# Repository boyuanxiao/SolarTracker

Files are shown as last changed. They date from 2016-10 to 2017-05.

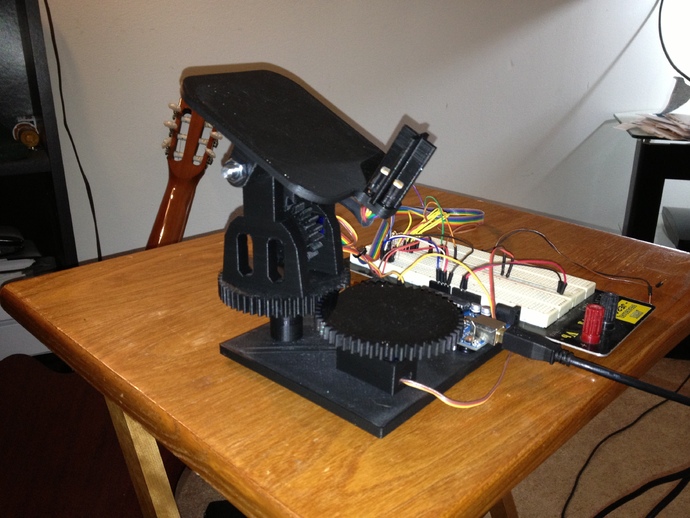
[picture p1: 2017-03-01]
cad/3dprint/images/Dual_Axis_Tracker_Front_preview_featured.jpg

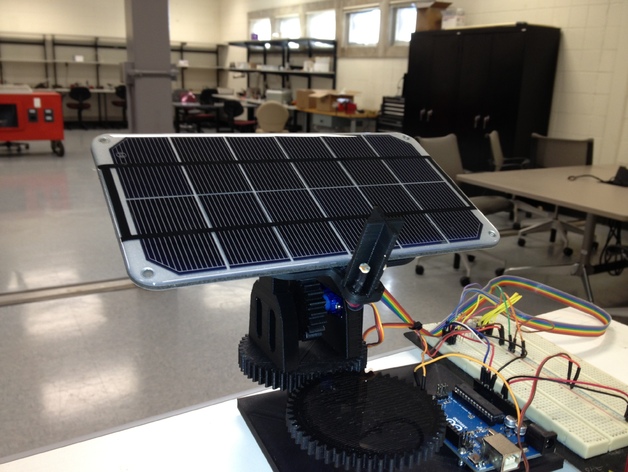
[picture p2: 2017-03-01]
cad/3dprint/images/photo_1_preview_featured.jpg

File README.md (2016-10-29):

# SolarTracker

Hardware and software for a servo controlled solar panel which orients itself to face directly towards the sun.

Plan to to have two modes of operation:

-Sensor: uses photodiode sensors to try and find the brightest source of light

-Auto: servo rotates as directed by a look up table based on the trajectory of the sun

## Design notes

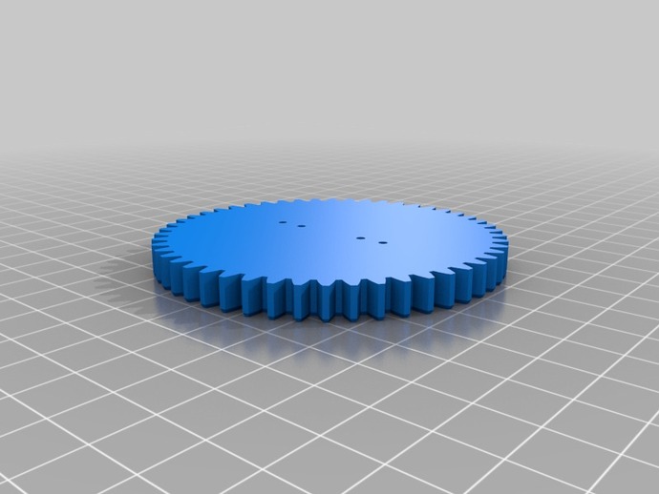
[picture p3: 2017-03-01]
cad/3dprint/images/Horz_Servo_Gear_preview_featured.jpg

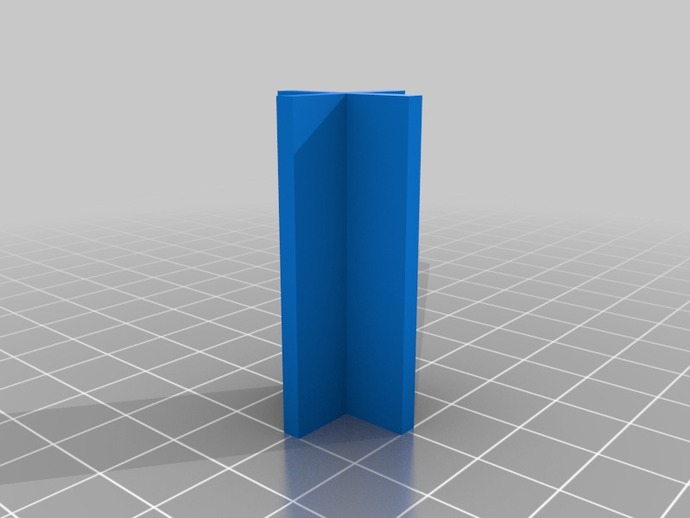
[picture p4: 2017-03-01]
cad/3dprint/images/LDR_Divider_preview_featured.jpg

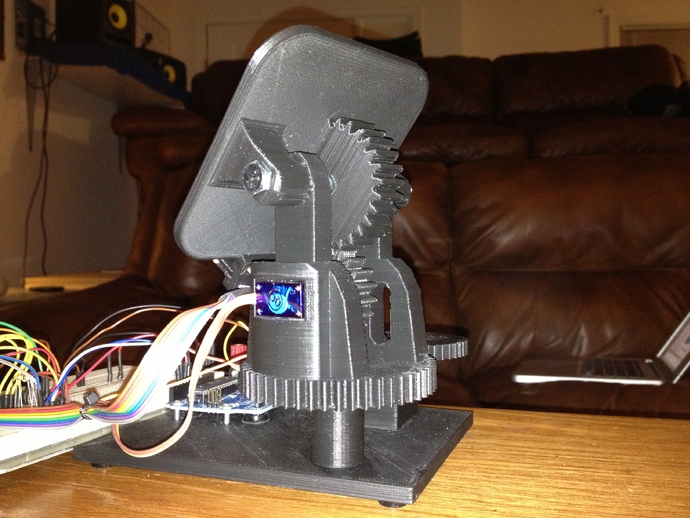
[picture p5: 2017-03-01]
cad/3dprint/images/Back_Right_preview_featured.jpg

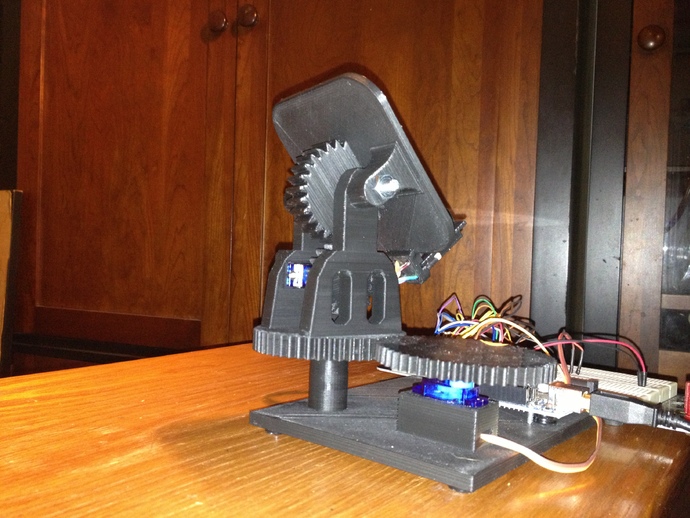
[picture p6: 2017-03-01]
cad/3dprint/images/Back_Left_preview_featured.jpg

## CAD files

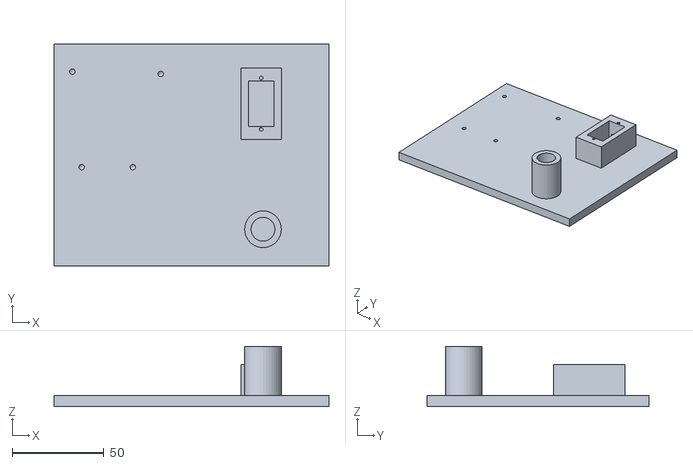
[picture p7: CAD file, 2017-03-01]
cad/3dprint/files/Tracker_Base.stl
150.0 x 121.0 x 33.0

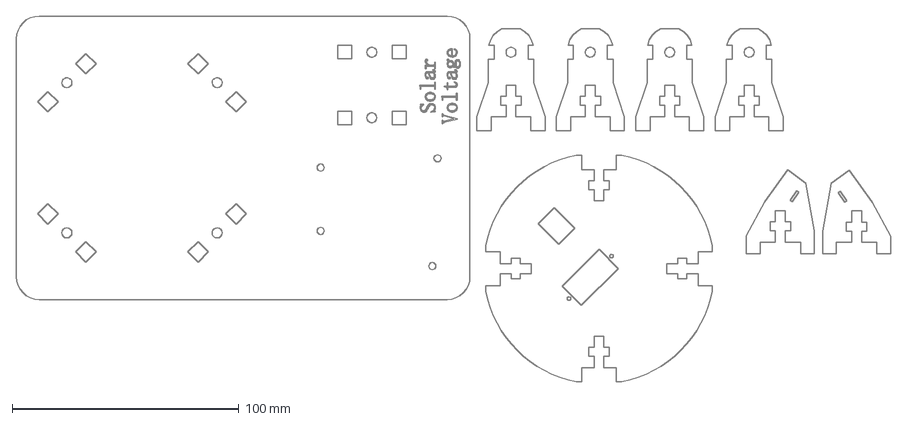
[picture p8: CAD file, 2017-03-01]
cad/lasercut/solartracker-bottom.svg.dxf
385.5 x 161.3 mm

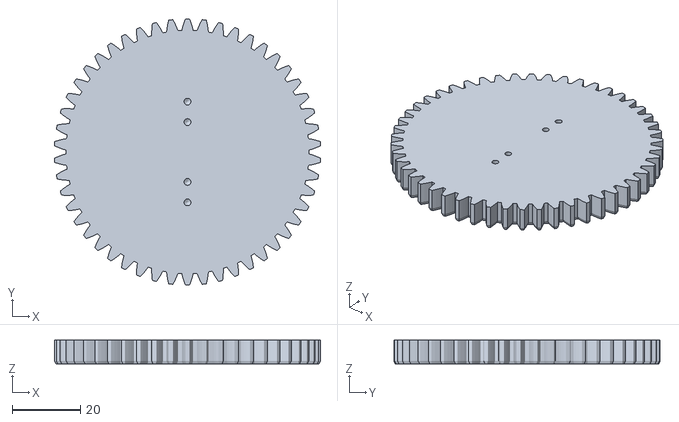
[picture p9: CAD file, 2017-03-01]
cad/3dprint/files/Horz_Servo_Gear.stl
77.9 x 78.0 x 7.00

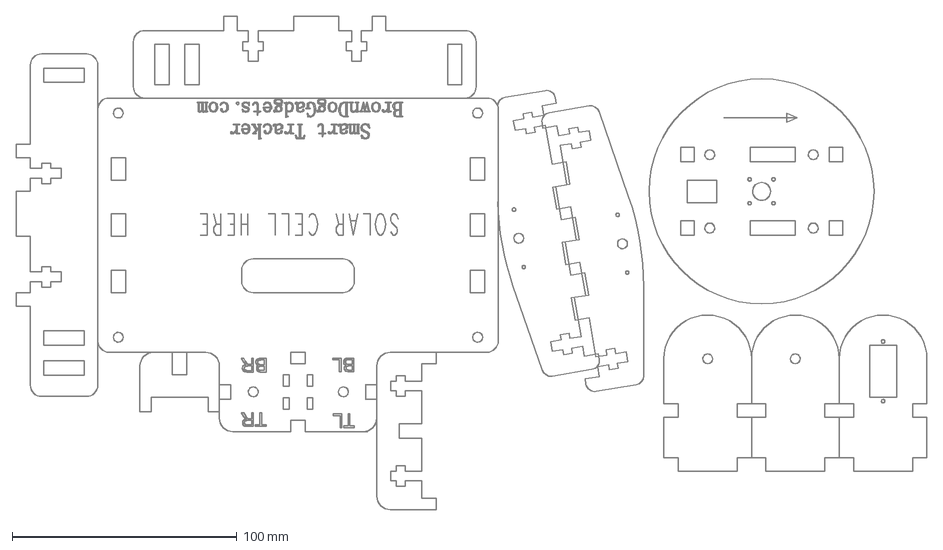
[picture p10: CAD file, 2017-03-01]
cad/lasercut/solartracker-top.svg.dxf
404.9 x 219.4 mm

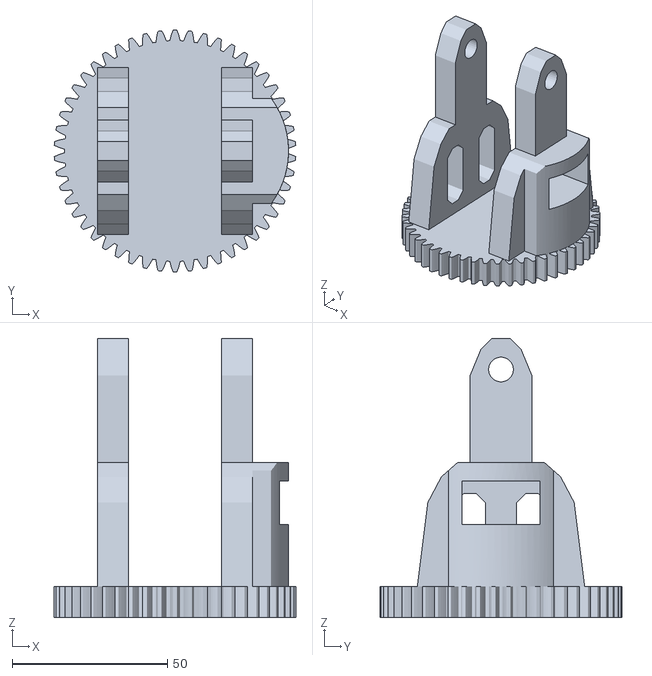
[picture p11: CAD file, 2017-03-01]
cad/3dprint/files/Base_Gear_and_Panel_Mount.stl
77.9 x 78.0 x 90.0

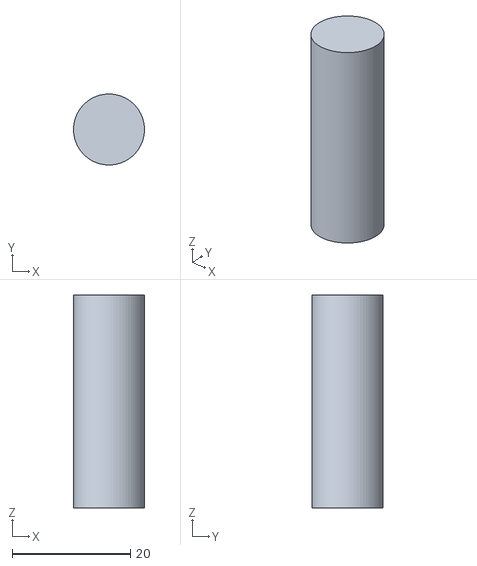
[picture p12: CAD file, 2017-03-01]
cad/3dprint/files/Base_Gear_Shaft.stl
12.0 x 12.0 x 36.0

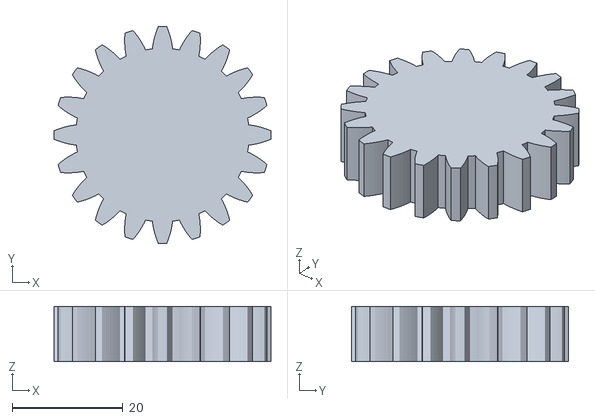
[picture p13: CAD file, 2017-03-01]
cad/3dprint/files/Vertical_Servo_Gear.stl
39.2 x 39.2 x 10.0

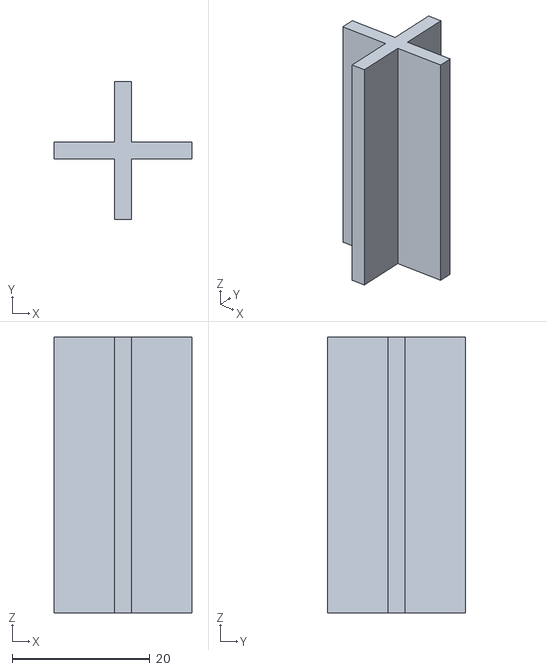
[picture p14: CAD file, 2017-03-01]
cad/3dprint/files/LDR_Divider.stl
20.0 x 20.0 x 40.0

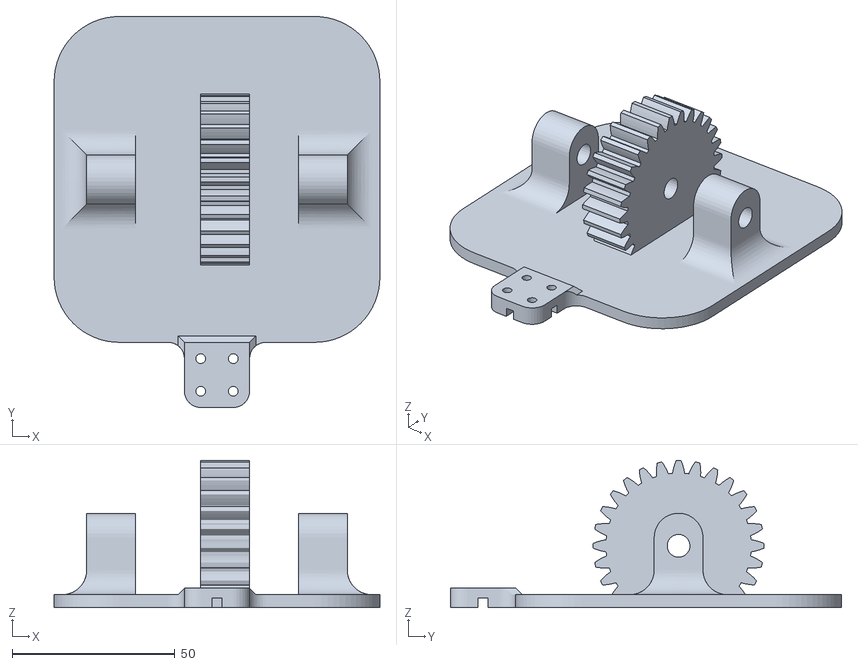
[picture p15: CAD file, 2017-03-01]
cad/3dprint/files/Panel_Bracket.stl
100.0 x 120.0 x 45.2

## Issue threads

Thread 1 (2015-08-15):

Power supply

boyuanxiao, 2015-08-15:
Servo needs 4.8 - 6V supply, battery voltage (Use switch mode supply with feedback with 3xAA, or 7805 with four.

Switch mode supply: more complex, try and choose resistors to avoid need for a feedback circuit. Higher current output with the MC33063 chip

7805: batt voltage could drop below 5V + dropout if load is high, simpler circuit.

boyuanxiao, 2015-08-27:
Use fixed output switch mode supply: SP6641A, or possibly LM1577 (latter is higher cost)

Closed 2015-08-27.

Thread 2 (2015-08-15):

3V3 to servo level level shifter

boyuanxiao, 2015-08-15:
Logic level for servo is the same as supply, STM32F07 chip runs off 3V3...

boyuanxiao, 2015-08-15:
Don't thin this is true for (modern) servos

Closed 2015-08-15.

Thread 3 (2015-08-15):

Work out current requirement of servo, converter, and battery at load

boyuanxiao, 2015-08-15:

boyuanxiao, 2015-08-27:
Servo draws ~100mA when idle, two = 200mA. The solar panel places a very small load. Estimate ~400mA maximum.

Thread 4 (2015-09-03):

Photodiode amplifier resistor

boyuanxiao, 2015-09-03:
1) Take samples over the course of the day at a (fixed angle), find resistor which gives greatest variation in voltage reading over the course of a day.

2) For a fixed source, find the response of the diode to light incident from different angles.

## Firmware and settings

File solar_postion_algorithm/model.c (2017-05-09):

/*Given a ime and position, this program should be able to
calculate the azimuth and elevation
of the sun*/

//For this model the input will take the form of a time struct, in the
// embedded application a TIME and DATE will be used for the starting time
// and a count used to determine time since then
// The servo has about 100 degrees of rotational range
// For the servo, let the horizontal have 90 degrees centred on South
// For vertical servo, let 90 be directly upwards (i.e. no change)

#include <stdlib.h>
#include <math.h>
#include <time.h>
#include <stdio.h>

#define PI 3.14159265
#define RANGE 160
#define HORIZONTAL_OFFSET -(180 - RANGE/2)
#define VERTICAL_OFFSET 0

#define VERBOSE 0

const float position_latitude = 52.1931;
const float position_longitude = -1.1382;
const float obliquity = 23.43704;

struct julian_date
{
	long julian_date_whole;
	float julian_date_frac;
};

void print_julian_date(struct julian_date *jd) {
	printf("Whole: %ld\n", jd->julian_date_whole);
	printf("Frac: %f\n", jd->julian_date_frac);
}

void update_julian_date(struct tm *time, struct julian_date *jd) {
	// Returns the current time in terms of Julian centuries since 12h UTC Jan 1 2000
	// The change in T over the course of a day is likely negligible: only run once a day (or even less frequently?)

	// Calculate the Julian date 
	int month, year;
	// Time structure holds years in terms of years from 1990
	year = 1900 + time->tm_year;
	month = time->tm_mon;
	if (time->tm_mon < 2) {
		month = time->tm_mon + 12;
		year -= 1;
	}
	int B;
	long julian_date_whole;
	float julian_date_frac;
	float T;
	B = 2 + year/100 + (year/100)/4;
	julian_date_whole = (int)(365.25 * (year + 4716)) + (int)(30.6001 * (month + 1)) + time->tm_mday + B - 1534;
	julian_date_frac = (float)((float)(time->tm_hour) + (float)(time->tm_min)/60.0 + (float)(time->tm_sec)/3600.0)/24.0 - 0.5;
	
	// update the current julian date
	jd->julian_date_whole = julian_date_whole;
	jd->julian_date_frac = julian_date_frac;
}

float get_julian_centuries(struct julian_date *jd) {
	// Calculate the number of centuries
	float T;
	T = ((float)(jd->julian_date_whole - 2451545) + jd->julian_date_frac) / 36525.0;
	return T;
}

float get_solar_longitude(float T) {
	// Returns the true longitude of the sun in ecliptic co-ordinates
	// Takes the number of centuries
	float longitude, solar_longitude, mean_anomaly, eq_of_centre;
	solar_longitude = fmod(280.46645 + 36000.76983 * T, 360.0);
	mean_anomaly = fmod(357.5291 + 35999.0503 * T, 360.0);
	eq_of_centre = 1.9146 * sin(mean_anomaly * PI/180.0) + 0.019993 * sin(2*mean_anomaly * PI/180.0) + 0.00029 * sin(3*mean_anomaly * PI/180.0);
	longitude = solar_longitude + eq_of_centre;
	
	return fmod(longitude, 360.0);
}

float approxiamate_hour_angle(struct tm *time) {
	return 180.0 - (15.0 * ( (float)time->tm_hour + (float)time->tm_min/60.0));
}

float get_hour_angle(struct julian_date *jd, float longitude) {
	// Calculates the hour angle in degrees, equal to Greenwich hour angle + longitude - right ascension
	float greenwich_hour_angle, right_ascension, hour_angle;
	greenwich_hour_angle = 280.46061837 + 0.98564736629 * ((float)(jd->julian_date_whole - 2451545)) + 360.98564736629 * jd->julian_date_frac;
	right_ascension = atan(sin(longitude * PI/180) * cos(obliquity * PI/180.0)/cos(longitude * PI/180.0));
	// Convert back in the range 0 -> PI and convert to degrees
	right_ascension = 180.0/PI * (right_ascension);
	hour_angle = greenwich_hour_angle - position_longitude - right_ascension;

	return fmod(hour_angle + 180.0, 360.0);
}

float get_declination(float longitude) {
	float declination;
	declination = 180.0/PI * asin(sin(obliquity * PI/180.0) * sin(longitude * PI/180.0));
	
	return declination;
}

float calculate_azimuth(float hour_angle, float declination) {
	float A, B, azimuth;
	A = cos(hour_angle * PI/180.0) * sin(position_latitude * PI/180.0);
	B = tan(declination * PI/180.0) * cos(position_latitude * PI/180.0);
	azimuth = 180.0/PI * (atan2(sin(hour_angle * PI/180.0), (A - B)) + PI);

	return 360.0 - azimuth;
}

void update_servo_angles(int *servo_elevation, int *servo_azimuth, float elevation, float azimuth) {
	int servo_angle_h, servo_angle_v;
	servo_angle_h = (int) azimuth + HORIZONTAL_OFFSET;
	servo_angle_v = (int) elevation;
	// Check if the values are out of bounds:
	if(servo_angle_h > RANGE || servo_angle_h < 0 || servo_angle_v < 0 || servo_angle_v > 90) {
		*servo_elevation = 0;
		*servo_azimuth = 0;
	} else {
		*servo_elevation = servo_angle_v;
		*servo_azimuth = servo_angle_h;
	}

}

float calculate_elevation(float hour_angle, float declination) {
	float A, B, elevation;
	A = sin(position_latitude * PI/180.0) * sin(declination * PI/180.0);
	B = cos(position_latitude * PI/180.0) * (cos(declination * PI/180.0) * cos(hour_angle * PI/180.0));
	elevation = 180/PI * asin(A + B);
	return elevation;
}

int main(int argc, char const *argv[])
{
	int i, second, minute, hour, day, month, year;
	int servo_angle_v, servo_angle_h;

	time_t raw_time;
	struct julian_date *jd;
	jd = malloc(sizeof(struct julian_date));
	
	struct tm *time_ptr;
	time_ptr = malloc(sizeof(struct tm));
	time(&raw_time);
	time_ptr = gmtime(&raw_time);
	time_ptr->tm_mon = 5;
	for (i = 3; i < 21; ++i) {
		time_ptr->tm_hour = i;
	
		float julian_centuries, solar_longitude, hour_angle, declination, azimuth, elevation;
		update_julian_date(time_ptr, jd);
		julian_centuries = get_julian_centuries(jd);
		solar_longitude = get_solar_longitude(julian_centuries);
		hour_angle = approxiamate_hour_angle(time_ptr);
		declination = get_declination(solar_longitude);
		azimuth = calculate_azimuth(hour_angle, declination);
		elevation = calculate_elevation(hour_angle, declination);
		update_servo_angles(&servo_angle_v, &servo_angle_h, elevation, azimuth);
		printf("Current Time:%2d:%2d\n", time_ptr->tm_hour, time_ptr->tm_min);
	#if VERBOSE	
		printf("Current Time: %4d:%2d:%2d:%2d:%02d\n", time_ptr->tm_year, time_ptr->tm_mon, time_ptr->tm_mday, time_ptr->tm_hour, time_ptr->tm_min);
		print_julian_date(jd);
		printf("Julian Centuries: %f\n", julian_centuries);
		printf("Solar Longitude: %f\n", solar_longitude);
		printf("Hour Angle: %f\n", hour_angle);
		printf("Declination: %f\n", declination);
	#endif
		
		printf("Solar Azimuth: %f\n", azimuth);
		printf("Solar Elevation: %f\n", elevation);

		printf("Servo Horizontal Angle: %d\n", servo_angle_h);
		printf("Servo Vertical Angle: %d\n", servo_angle_v);
		printf("\n");
	}
	return 0;
}

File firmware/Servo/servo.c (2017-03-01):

/*
 * ChibiOS/Servo is a small library to easily interface RC servos with ChibiOS/RT.
 *
 * BSD licensed
 *
 * Author: Joel Bodenmann aka Tectu   <joel@unormal.org>
 */

#include "servo.h"

static PWMConfig pwmcfg = {
    1000000,	// 1MHz PWM clock frequency
    20000,		// PWM period 20 milliseconds
    (pwmcallback_t) NULL,
    {}, // PWM Channel config
    0,
    0
    // (PWMChannelConfig*) NULL
};

void servoInit(Servo *servo) {
	/* create the channel configuration */
	PWMChannelConfig chcfg = { PWM_OUTPUT_ACTIVE_HIGH, NULL };
	pwmcfg.channels[servo->pwm_channel] = chcfg;
	palSetPadMode(servo->port, servo->pin, PAL_MODE_OUTPUT_PUSHPULL);

	/* start the PWM unit */
	pwmStart(servo->pwm_driver, &pwmcfg);
}

void servoSetValue(Servo *servo, uint16_t value) {
	/* a bit of safty here */
	if(value > servo->max)
		value = servo->max;
	if(value < servo->min)
		value = servo->min;

	pwmEnableChannel(servo->pwm_driver, servo->pwm_channel, (pwmcnt_t)value);
}

void servoSetMax(Servo *servo, uint16_t value) {
	servo->max = value;	
}

void servoSetMin(Servo *servo, uint16_t value) {
	servo->min = value;
}

uint16_t servoGetMax(Servo *servo) {
	return (servo->max);
}

uint16_t servoGetMin(Servo *servo) {
	return (servo->min);
}

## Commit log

2015-08-01 first sketch of amplifier circuit
    [solarTracker.sch]
2015-08-01 use stm32d100 mcu, switch between four analog inputs using multiplexer, separate analog and digital gnds
    [solarTracker.sch]
2015-08-01 add 2nd order Butterworth filter, change first amp to lm324
    [photodiode.sch, solarTracker.sch]
2015-08-01 fix hierachal sheet labelling
    [photodiode.sch, solarTracker.sch]
2015-08-01 change filter resistor to correct value, reduce cap size (and cost)
    [photodiode.sch, solarTracker.sch]
2015-08-02 add servo
    [photodiode.sch, solarTracker.sch]
2015-08-03 6V converter for servo power
    [photodiode.sch, solarTracker.sch]
2015-08-04 finish power circuit
    [solarTracker.sch]
2015-08-04 add 3v3 converter
    [photodiode.sch, solarTracker.sch]
2015-08-12 fix step up circuit
    [solarTracker.sch]
2015-08-13 example servo driver
2015-08-14 debugger circuit
    [photodiode.sch, solarTracker.sch]
2015-08-14 replace servo with conn
    [solarTracker.sch]
2015-08-28 lm2577 regulator for 6V supply
    [photodiode.sch, solarTracker.sch]
2015-08-28 some farnell codes
    [solarTracker.sch]
2017-01-05 switch to LM2596 step down converter, Vbatt to be 9V alkaline
    [solarTracker.sch]
2017-01-07 connect mcu to servo and mux, add level shifter
    [photodiode.sch, solarTracker.sch]
2017-01-07 change BATT to 3V3 regulator
    [solarTracker.sch]
2017-01-08 add breakout header to interface with dev board
    [solarTracker.sch]
2017-01-16 fix µcu farnell code
    [photodiode.sch, solarTracker.sch]
2017-02-05 footprint generation, chibiOS and chibiOS-servo libraries
    [photodiode.sch, solarTracker.kicad_pcb, solarTracker.sch]
2017-03-01 Changes to board, add footprints
    [Base_Gear_Shaft.stl, Base_Gear_and_Panel_Mount.stl, Horz_Servo_Gear.stl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]
2017-05-14 Code to drive the solartracker (using solar position algorithm) in Arduino. Tested using current date.
